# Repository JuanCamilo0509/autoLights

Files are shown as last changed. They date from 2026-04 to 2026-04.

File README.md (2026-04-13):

# Automatic light module
This project aims to be a plug and play wall switch based on the esp8266 board and using MQTT protocol for communications.

```
.
├── Hardware
│   └── autoLightPCB(Kicad)
├── README.md
└── software
    ├── lightModule(esp8266)
    └── mosquittoServer
        └── mosquitto.conf
```

This project has two main directories:
    - Software: Two main sub-directories, the light-Module where the code for the esp is maintain, and the "mosquitto-Server" with the ".conf" file for the server. 
    - Hardware: In this repository you can find the PCB layout for the board and the 3d model for the case.
## How to configure an ESP?
1. Upload the code to the esp.
2. When power, the esp will create a WIFI entrance call "esp".
3. Connect to "esp" Network.
4. Using any browser go to `htpp://192.168.4.1/`.
5. Fill all the information for the esp. (You can test the light to know which light you're setting up).
6. Send all the information. The esp should restart with all the information saved.
7. You're done, try to change the state from your phone. (I recommend using IoT MQTT Panel to test it).

## Features
- HTTP Server on SoftAP mode when the variables aren't on the esp memory to set them up: (SSID, WiFi password, broker and topic).
<table>
  <tr>
    <td>
      
    </td>
    <td>
      
    </td>
  </tr>
</table>

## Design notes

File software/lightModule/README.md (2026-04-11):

# Light Module
How to use 
Configure the project

```
make menuconfig
```

- Under configuration set:
    - Broker URL: The URL of the broker to connect to.
    - Topic URL: Topic where the ESP should be focus on.
    - Wifi SSID: The name of your network.
    - Wifi PassWord: Password for the Wifi Network.

## Build and Flash

Build the project and flash it to the board, then run monitor tool to view serial output:
```
make flash monitor
```
(To exit the serial monitor, type Ctrl-].)

## Features
- Publish and subscription to a topic.
    - GPIO0 publish to the topic through a interrupt routine that toggles the stead of the light. 
    - GPIO2 is the output pin for the signal to change the light setup.

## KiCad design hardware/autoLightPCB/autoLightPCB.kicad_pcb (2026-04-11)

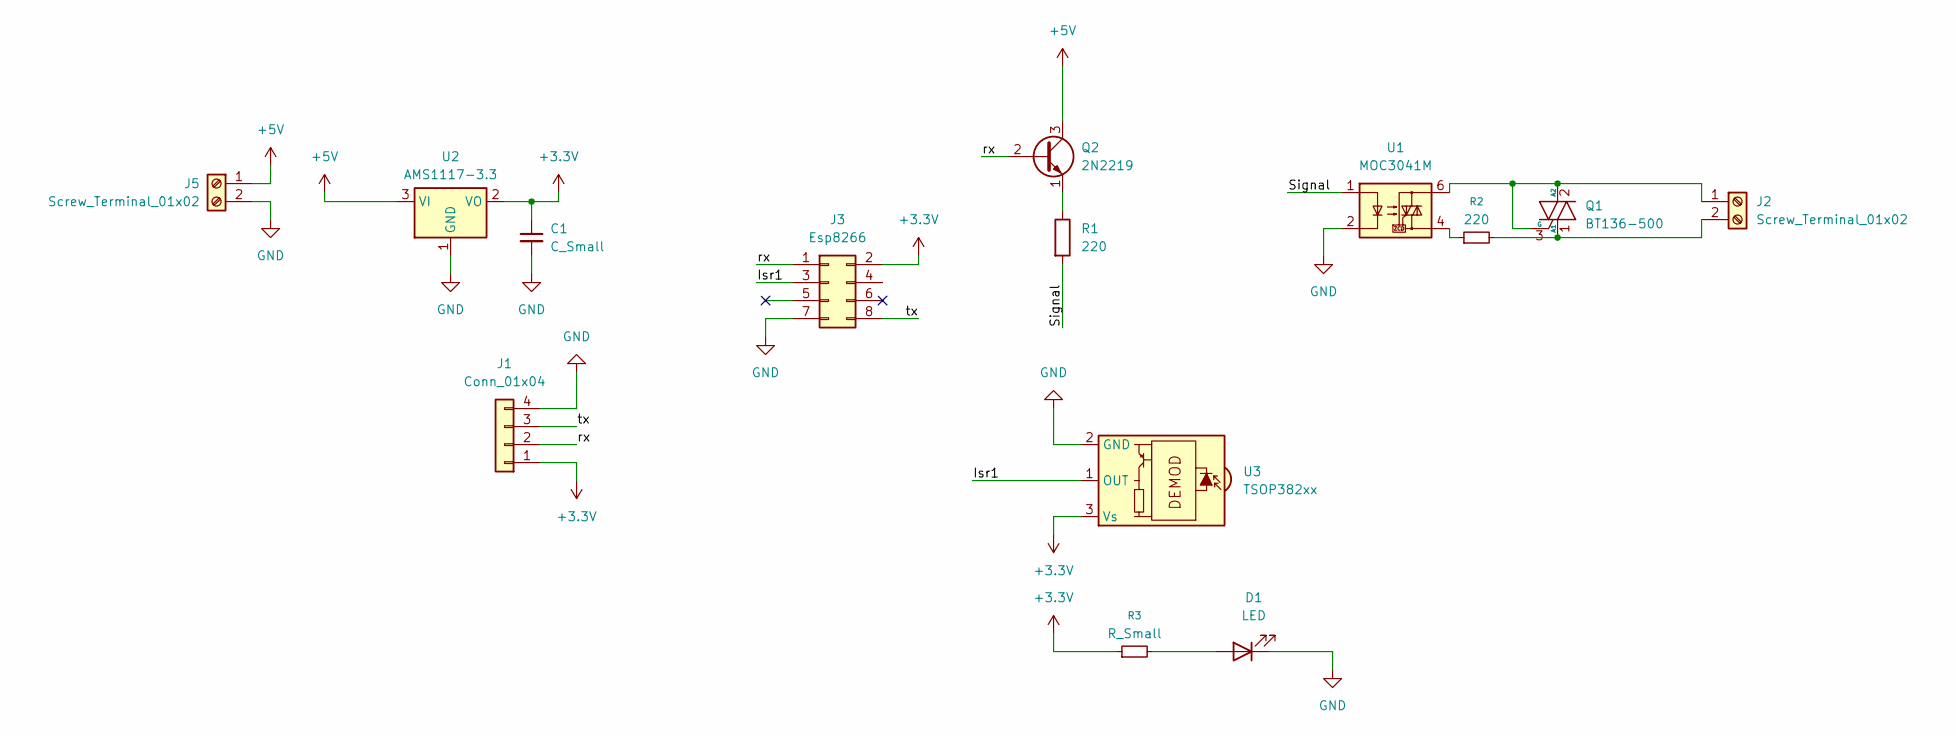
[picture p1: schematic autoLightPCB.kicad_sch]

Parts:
C1: C_Small; C_0504_1310Metric
D1: LED; LED_D5.0mm
J1: Conn_01x04; PinHeader_1x04_P1.27mm_Vertical
J2, J5: Screw_Terminal_01x02; PhoenixContact_SPT_1.5_2-H-3.5_1x02_P3.5mm_Horizontal
J3: Esp8266; Wuerth_WR-PHD_613008216921_Large_2x04_P2.54mm_Vertical
Q1: BT136-500; TO-220-3_Vertical
Q2: 2N2219; TO-92L_Inline
R1, R2: 220; R_0603_1608Metric
R3: R_Small; R_0603_1608Metric
U1: MOC3041M; DIP-6_W7.62mm_LongPads
U2: AMS1117-3.3; SOT-223-3_TabPin2
U3: TSOP382xx; Vishay_MINICAST-3Pin

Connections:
+3.3V: C1.1, J1.1, J3.2, R3.1, U2.2 (VO), U3.3 (Vs)
+5V: J5.1, Q2.3 (C), U2.3 (VI)
/Isr1: J3.3, U3.1 (OUT)
/Signal: R1.2, U1.1
/rx: J1.2, J3.1, Q2.2 (B)
/tx: J1.3, J3.8
GND: C1.2, D1.1 (K), J1.4, J3.7, J5.2, U1.2, U2.1 (GND), U3.2 (GND)
unnamed: D1.2 (A), R3.2
unnamed: J2.1, Q1.2 (A2), Q1.3 (G), U1.6
unnamed: J2.2, Q1.1 (A1), R2.2
unnamed: Q2.1 (E), R1.1
unnamed: R2.1, U1.4

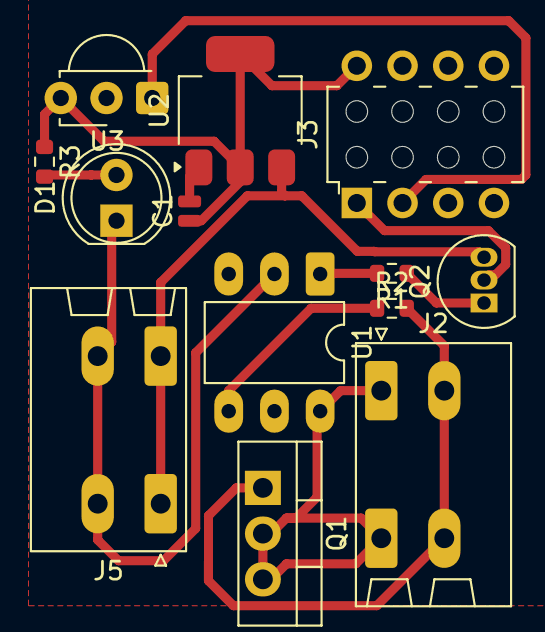
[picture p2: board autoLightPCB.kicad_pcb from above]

Board: 2 copper layers, 13 parts (0 on the bottom side), 11 nets.

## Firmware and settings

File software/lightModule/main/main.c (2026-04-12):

#include "connect.h"
#include "data.h"
#include "espServer.h"
#include "gpio.h"
#include "mqtt.h"
#include "sdkconfig.h"

static xQueueHandle gpio_evt_queue = NULL;

static void gpio_isr_handler(void *arg) {
  uint32_t gpio_num = (uint32_t)arg;
  gpio_isr_handler_remove(gpio_num);
  xQueueSendFromISR(gpio_evt_queue, &gpio_num, NULL);
}

static void light_toggle_task(void *arg) {
  for (;;) {
    ulTaskNotifyTake(pdTRUE, portMAX_DELAY);

    int new_state = !get_light_state();
    update_light_state(new_state);
    get_light_state_str();

    const char *msg = (new_state == 1) ? "On" : "Off";
    esp_mqtt_client_handle_t client = get_client();
    if (client != NULL) {
      esp_mqtt_client_publish(client, device_config.topic, msg, 0, 1, 0);
    }

    vTaskDelay(pdMS_TO_TICKS(150));
    gpio_isr_handler_add(0, gpio_isr_handler, (void *)0);
  }
}

static void factory_reset_task(void *arg) {
  for (;;) {
    ulTaskNotifyTake(pdTRUE, portMAX_DELAY);
    nvs_flash_erase();
    esp_restart();
  }
}

static TaskHandle_t light_task_handle = NULL;
static TaskHandle_t factory_task_handle = NULL;

static void gpios_tasks(void *arg) {
  uint32_t io_num;
  for (;;) {
    if (xQueueReceive(gpio_evt_queue, &io_num, portMAX_DELAY)) {
      if (io_num == 0) {
        if (light_task_handle != NULL) {
          xTaskNotifyGive(light_task_handle);
        }
      } else if (io_num == 5) {
        if (factory_task_handle != NULL) {
          xTaskNotifyGive(factory_task_handle);
        }
      }
    }
  }
};

int is_config_complete() {
  nvs_handle my_handle;
  esp_err_t err;

  err = nvs_open("storage", NVS_READONLY, &my_handle);
  if (err != ESP_OK) {
    return 0;
  }

  size_t ssid_len = 0;
  size_t pass_len = 0;
  size_t broker_len = 0;
  size_t topic_len = 0;

  esp_err_t e1 = nvs_get_str(my_handle, "ssid", NULL, &ssid_len);
  esp_err_t e2 = nvs_get_str(my_handle, "password", NULL, &pass_len);
  esp_err_t e3 = nvs_get_str(my_handle, "broker", NULL, &broker_len);
  esp_err_t e4 = nvs_get_str(my_handle, "topic", NULL, &topic_len);

  nvs_close(my_handle);

  if (e1 == ESP_OK && ssid_len > 1 && e2 == ESP_OK && pass_len > 1 &&
      e3 == ESP_OK && broker_len > 1 && e4 == ESP_OK && topic_len > 1) {
    return 1;
  }
  return 0;
}

void app_main(void) {
  ESP_ERROR_CHECK(nvs_flash_init());

  ESP_ERROR_CHECK(esp_netif_init());

  gpio_evt_queue = xQueueCreate(10, sizeof(uint32_t));
  initialize_gpio();
  xTaskCreate(light_toggle_task, "light_task", 2048, NULL, 9,
              &light_task_handle);
  xTaskCreate(factory_reset_task, "factory_task", 2048, NULL, 8,
              &factory_task_handle);
  xTaskCreate(gpios_tasks, "gpio_task", 2048, NULL, 10, NULL);
  gpio_isr_handler_add(0, gpio_isr_handler, (void *)0);
  gpio_isr_handler_add(5, gpio_isr_handler, (void *)5);

  if (is_config_complete()) {
    load_config_from_nvs();
    wifi_init_sta();
    mqtt_app_start();
  } else {
    wifi_init_softap();
    start_webserver();
  };
}

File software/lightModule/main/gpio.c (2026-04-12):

#include "gpio.h"

int light_state = 0;

void initialize_gpio() {
  gpio_config_t io_confI = {};
  io_confI.intr_type = GPIO_INTR_NEGEDGE;
  io_confI.mode = GPIO_MODE_INPUT;
  io_confI.pull_down_en = 0;
  io_confI.pull_up_en = 1;
  io_confI.pin_bit_mask = (1ULL << 0);
  gpio_config(&io_confI);

  io_confI.intr_type = GPIO_INTR_DISABLE;
  io_confI.mode = GPIO_MODE_OUTPUT;
  io_confI.pull_down_en = 0;
  io_confI.pull_up_en = 0;
  io_confI.pin_bit_mask = (1ULL << 2);
  gpio_config(&io_confI);

  io_confI.intr_type = GPIO_INTR_NEGEDGE;
  io_confI.mode = GPIO_MODE_INPUT;
  io_confI.pull_down_en = 0;
  io_confI.pull_up_en = 1;
  io_confI.pin_bit_mask = (1ULL << 5);
  gpio_config(&io_confI);

  gpio_install_isr_service(0);
}

void update_light_state(int new_state) {
  light_state = new_state;
  gpio_set_level(2, !light_state);
}

int get_light_state(void) { return light_state; }

const char *get_light_state_str(void) {
  return (light_state == 1) ? "On" : "Off";
}

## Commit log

2026-04-11 Main functionality (pcb and esp code).
    [autoLightPCB.kicad_pcb, autoLightPCB.kicad_sch]
2026-04-12 Fix #2. Creating a new ISR on gpio5 to erase nvs. Using gpio5 to reset when the user wants to reconfigurated the esp.
    [gpio.c, main.c]
2026-04-13 Fix #1. Fixing the button to change light state. Deleting the webPage.
